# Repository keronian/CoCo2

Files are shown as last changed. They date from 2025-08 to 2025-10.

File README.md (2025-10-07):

# CoCo2

This is my version of two separate composite video mod boards for the Tandy Color Computer 2, based initially on calphool's work.  One board is, like his, to replace a vertical RF Modulator, the other is to replace a horizontal RF Modulator.  The circuit design is the same for both.

I started with calphool's work, but re-did the whole board in KiCad.  The vertical board has some support PCBs that can be fabricated, and they serve as grounding points... You can use the board without them, but you'd need to use a grounding wire.  Horizontal board is mounted by taking a solder lug, bending the tab 90 degrees, and screwing it up into the board through the standoff (which should be soldered from the top for the best strength).
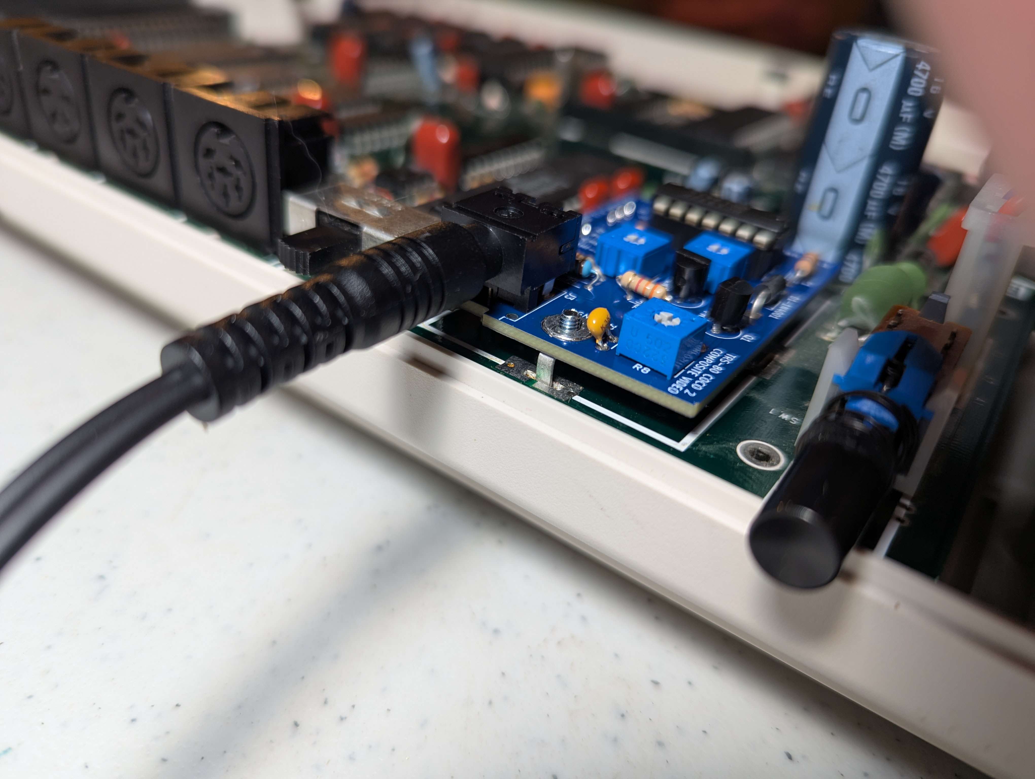
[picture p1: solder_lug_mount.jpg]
Lug Mount

Grounding seems to work great so far, we'll see if I have issues with it backing out.  This is the first time I've tried doing anything with KiCad, so... hopefully it's not terrible.

With some advice from captainkirchoff in Discord, I've tweaked some resistors and added a circuit that let the channel select switch disable color.  Please note that this is really only for monochrome monitors, as it completely suppresses the chroma signal, which causes some weird artifacting in many color monitors.

Vertical version has also had a switch added to replicate the same functionality for that board... I used a SLW-1298856-5A-RA-N-D (will be in the BOM) - Had to import the footprint for it, so if you work on the board you'll need to grab that library from them.

Note that you can increase the value of the C4 capacitor and get better noise reduction (suggested value can go up to 10uF), but ceramic caps are still preferred.

The vertical board's support brackets are set up so that you can slip a thin metal tab (I cut a piece off of one of the solder lugs in the BOM) into the slot after it's slotted into the board, then you add solder to create the joint.
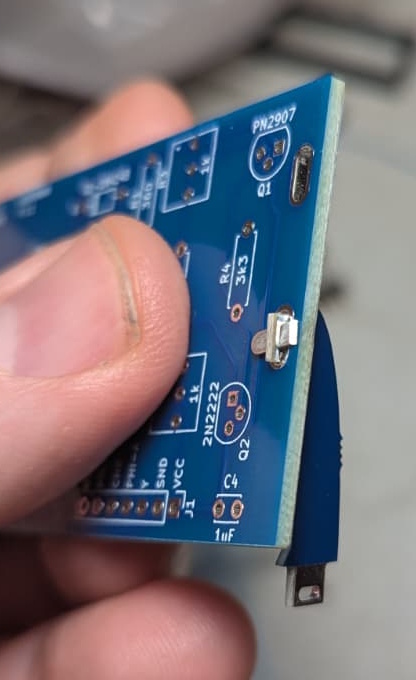
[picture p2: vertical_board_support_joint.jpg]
Vertical Board Support Joint


Overall fitment suggestion would be to solder the smaller supports to the back side of the board along with the headers (the size of header is VERY important, the BOM has the right size) - Then you slip it into place on the board with the longer supports just dry fit.. make sure everything is where you want it, then solder the longer supports into place, and finish by soldering the underside of the motherboard.  On mine, this resulted in a very solidly mounted board that would hardly wiggle.

https://www.digikey.com/en/mylists/list/GH709EISJW - This is the parts list for the board, with the updated transistors to make sure they were options that would be available and an audio jack that should fit the footprint I had on the board.

# Horizontal Board pics

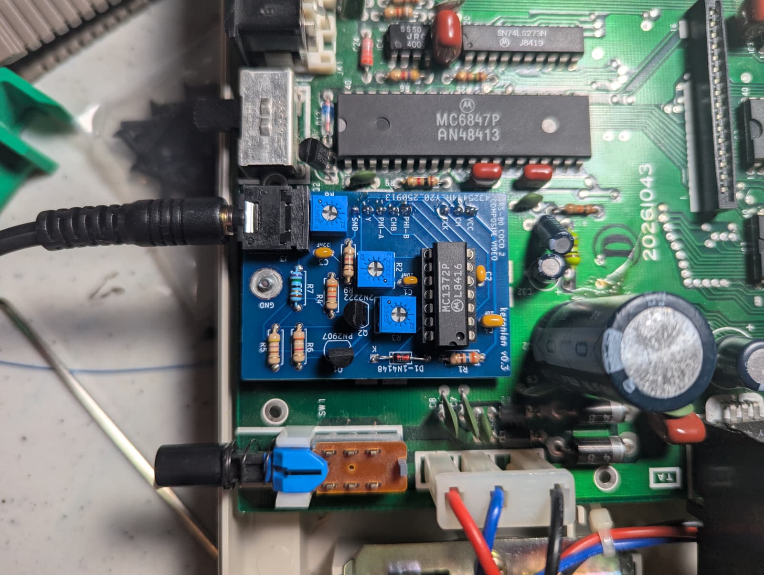
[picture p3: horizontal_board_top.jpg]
Horizontal Board Top

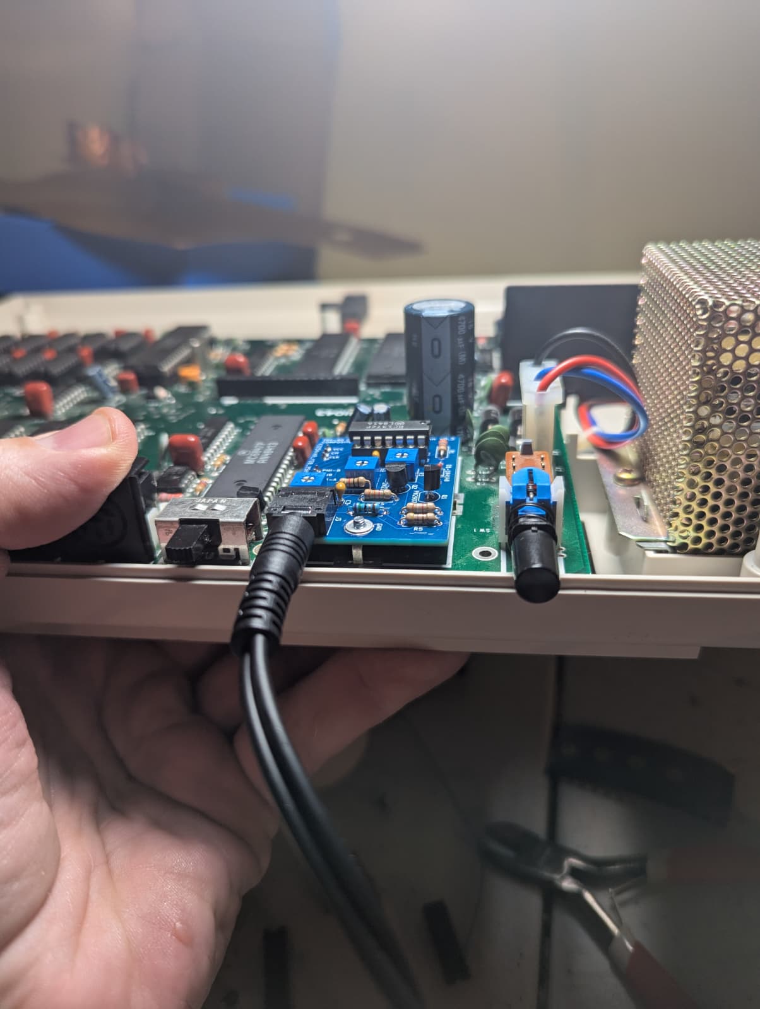
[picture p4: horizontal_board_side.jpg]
Horizontal Board Side


# Vertical Board pics

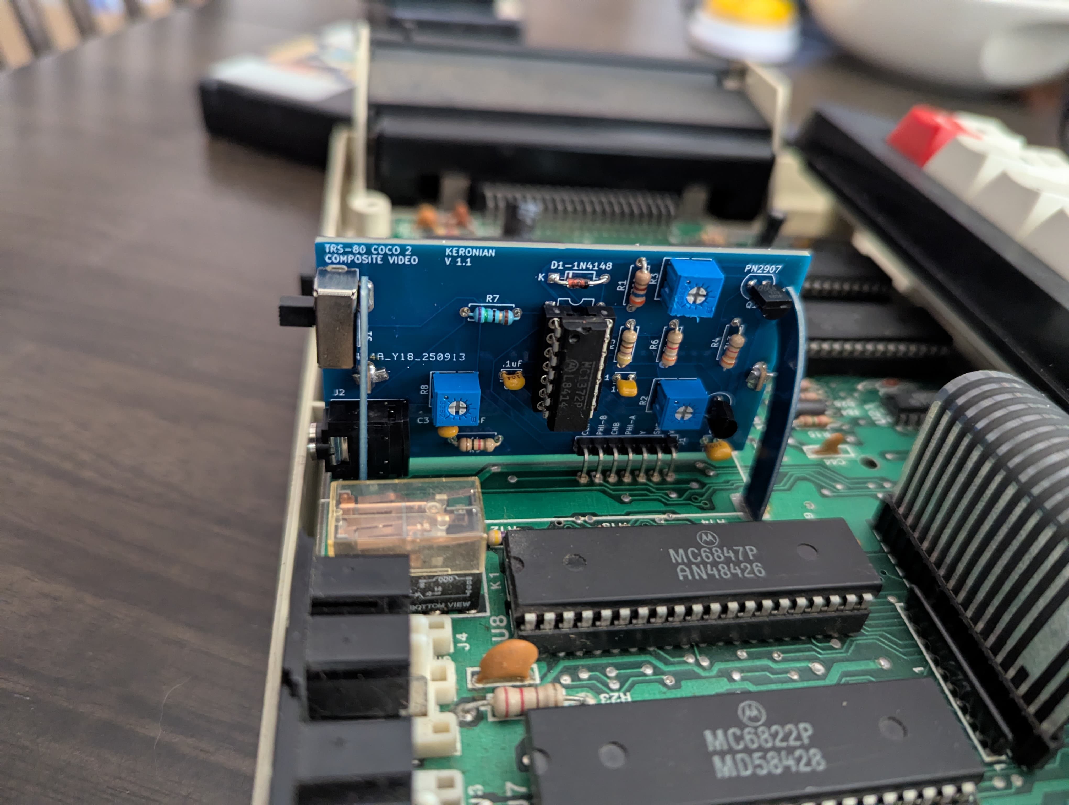
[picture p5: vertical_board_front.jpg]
Vertical Board Top

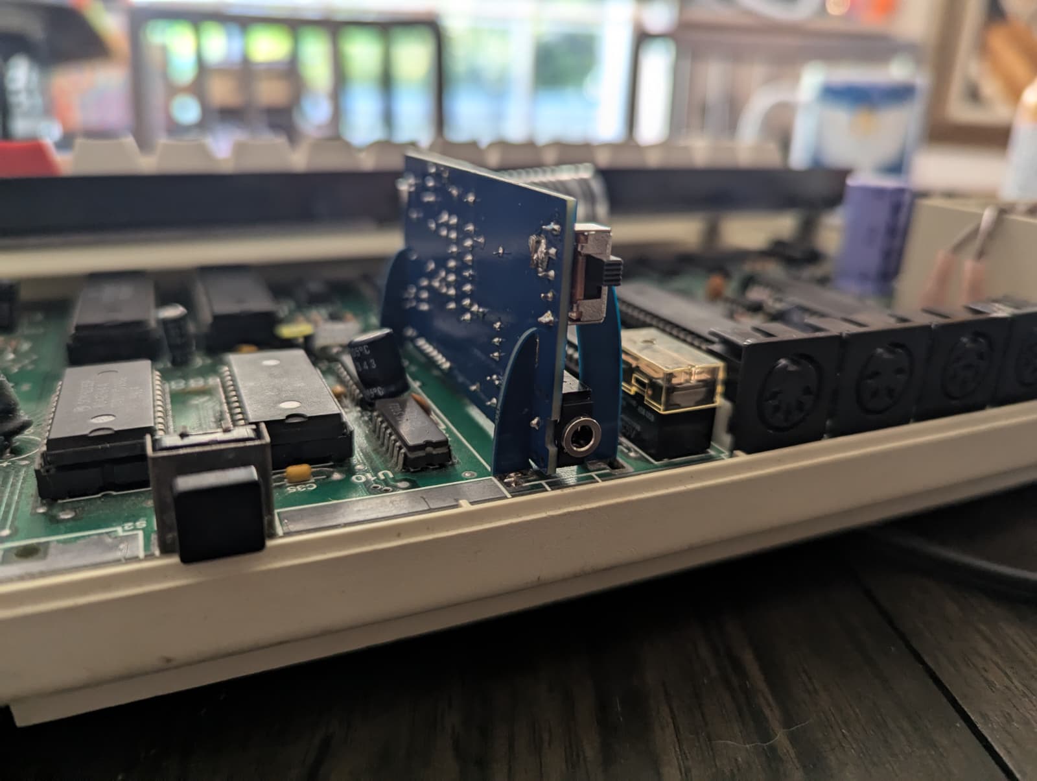
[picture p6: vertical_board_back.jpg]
Vertical Board Side


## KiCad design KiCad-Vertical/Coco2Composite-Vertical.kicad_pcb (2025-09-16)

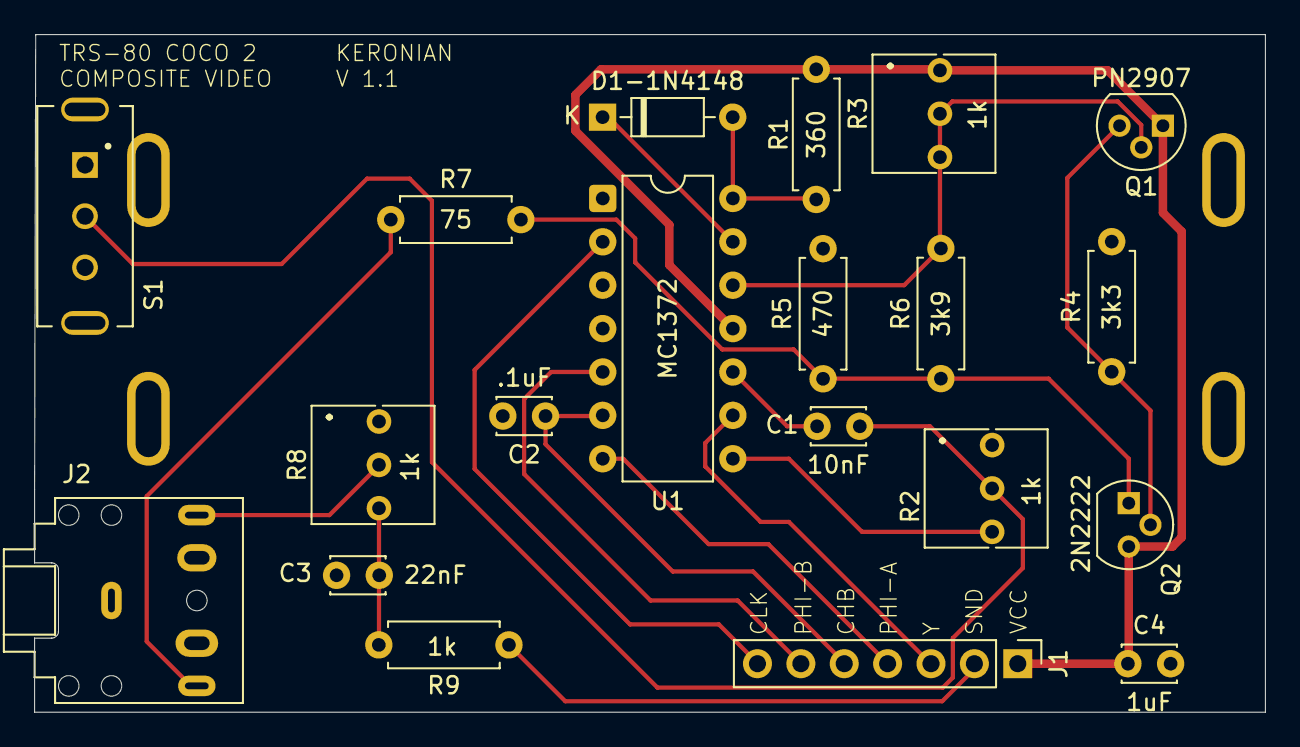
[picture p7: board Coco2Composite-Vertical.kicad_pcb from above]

Board: 2 copper layers, 72.1 x 39.7 mm, 20 parts (0 on the bottom side), 19 nets.

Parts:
C1: 10nF; C_Disc_D3.0mm_W2.0mm_P2.50mm
C2: .1uF; C_Disc_D3.0mm_W2.0mm_P2.50mm
C3: 22nF; C_Disc_D3.0mm_W2.0mm_P2.50mm
C4: 1uF; C_Disc_D3.0mm_W2.0mm_P2.50mm
D1-1N4148: 1N4148; D_DO-35_SOD27_P7.62mm_Horizontal
J1: TO_COCO2; PinHeader_1x07_P2.54mm_Vertical
J2: AUDIO_JACK_3.5MM_KIT; Jack_3.5mm_CUI_SJ1-3525N_Horizontal
Q1: PN2907; TO-92
Q2: 2N2222; TO-92
R1: 360; R_Axial_DIN0207_L6.3mm_D2.5mm_P7.62mm_Horizontal
R2, R3, R8: 1k; Potentiometer_Bourns_3266Y_Vertical
R4: 3k3; R_Axial_DIN0207_L6.3mm_D2.5mm_P7.62mm_Horizontal
R5: 470; R_Axial_DIN0207_L6.3mm_D2.5mm_P7.62mm_Horizontal
R6: 3k9; R_Axial_DIN0207_L6.3mm_D2.5mm_P7.62mm_Horizontal
R7: 75; R_Axial_DIN0207_L6.3mm_D2.5mm_P7.62mm_Horizontal
R9: 1k; R_Axial_DIN0207_L6.3mm_D2.5mm_P7.62mm_Horizontal
S1: SLW-1298856-5A-RA-N-D; SW_SLW-1298856-5A-RA-N-D
U1: MC1372; DIP-14_W7.62mm

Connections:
/CHB: C2.1, J1.5, U1.6 (COL_REF_IN)
/CLK: J1.7, U1.2 (OSC_IN)
/COMP_OUT: J2.T, R7.1
/PHI-A: J1.4, U1.7 (COL_A_IN)
/PHI-B: J1.6, U1.5 (COL_B_IN)
/SND: J1.2, R9.1
/SND_OUT: J2.R, R8.2
/Y: J1.3, U1.9 (LUM_IN)
GND: C2.2, C3.2, C4.2, J2.S, R2.1, R4.2, R5.2, R8.1, S1.3, S1.SH1, S1.SH2, U1.4 (GND)
unnamed: C1.2, R2.2, S1.2
unnamed: C3.1, R8.3, R9.2
unnamed: D1-1N4148.2 (A), R1.2, U1.14 (RF_TANK_2)
unnamed: D1-1N4148.1 (K), U1.13 (RF_TANK_1)
unnamed: Q1.3, Q2.2 (B), R4.1
unnamed: Q2.1 (E), R5.1, R6.1, R7.2
unnamed: C1.1, U1.10 (CHROM_IN)
unnamed: R2.3, U1.8 (CHROM_MOD_OUT)
unnamed: Q1.2, R3.2, R3.3, R6.2, U1.12 (RF_OUT)
VCC: C4.1, J1.1, Q1.1, Q2.3 (C), R1.1, R3.1, U1.11 (VCC)

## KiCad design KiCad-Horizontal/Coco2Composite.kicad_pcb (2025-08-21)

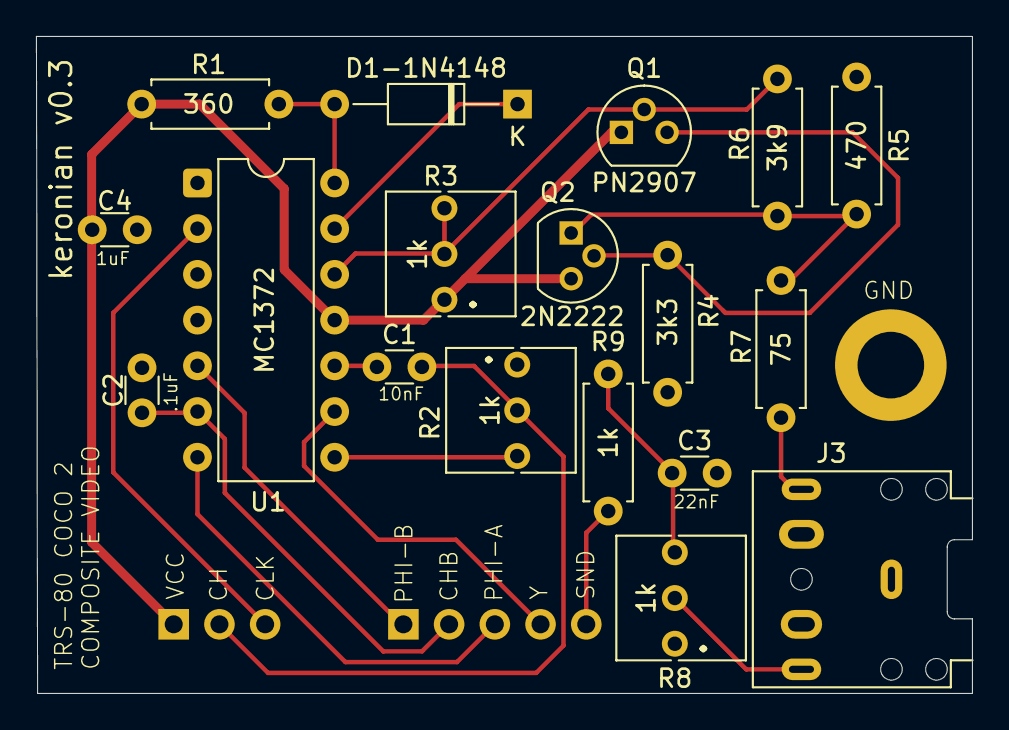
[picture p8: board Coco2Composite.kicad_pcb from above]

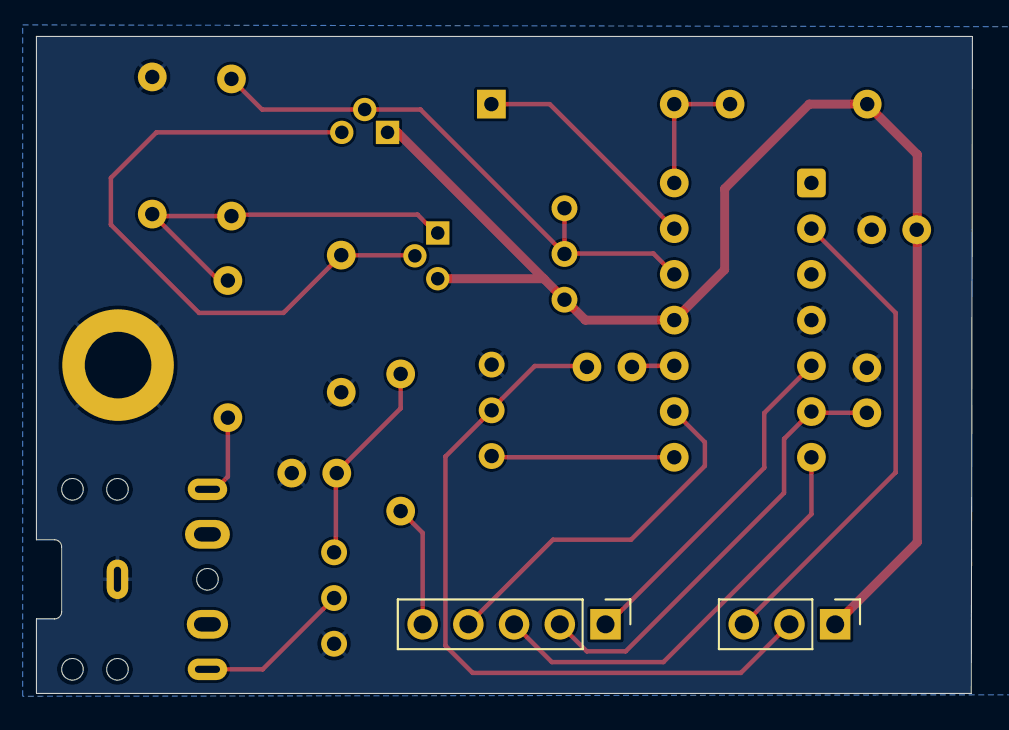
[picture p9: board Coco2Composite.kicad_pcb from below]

Board: 2 copper layers, 52.0 x 36.5 mm, 21 parts (2 on the bottom side), 19 nets.

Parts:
C1: 10nF; C_Disc_D3.0mm_W1.6mm_P2.50mm
C2: .1uF; C_Disc_D3.0mm_W1.6mm_P2.50mm
C3: 22nF; C_Disc_D3.0mm_W1.6mm_P2.50mm
C4: 1uF; C_Disc_D3.0mm_W1.6mm_P2.50mm
D1-1N4148: 1N4148; D_DO-35_SOD27_P10.16mm_Horizontal
J1: MA03-1; PinHeader_1x03_P2.54mm_Vertical
J2: MA05-1; PinHeader_1x05_P2.54mm_Vertical
J3: AUDIO_JACK_3.5MM_PTH; Jack_3.5mm_CUI_SJ1-3525N_Horizontal
PAD1: 2,54/0,8; MountingHole_3.7mm_Pad
Q1: PN2907; TO-92
Q2: 2N2222; TO-92
R1: 360; R_Axial_DIN0207_L6.3mm_D2.5mm_P7.62mm_Horizontal
R2, R3, R8: 1k; Potentiometer_Bourns_3266Y_Vertical
R4: 3k3; R_Axial_DIN0207_L6.3mm_D2.5mm_P7.62mm_Horizontal
R5: 470; R_Axial_DIN0207_L6.3mm_D2.5mm_P7.62mm_Horizontal
R6: 3k9; R_Axial_DIN0207_L6.3mm_D2.5mm_P7.62mm_Horizontal
R7: 75; R_Axial_DIN0207_L6.3mm_D2.5mm_P7.62mm_Horizontal
R9: 1k; R_Axial_DIN0207_L6.3mm_D2.5mm_P7.62mm_Horizontal
U1: MC1372; DIP-14_W7.62mm

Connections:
/CH: C1.2, J1.2, R2.2
/CHB: C2.1, J2.2, U1.6 (COL_REF_IN)
/CHROM_IN: C1.1, U1.10 (CHROM_IN)
/CHROM_MOD_OUT: R2.3, U1.8 (CHROM_MOD_OUT)
/CLK: J1.3, U1.2 (OSC_IN)
/COMP_OUT: J3.T, R7.2
/PHI-A: J2.3, U1.7 (COL_A_IN)
/PHI-B: J2.1, U1.5 (COL_B_IN)
/Q1_E: Q1.3, Q2.2 (B), R4.2
/Q2_E: Q2.1 (E), R5.2, R6.2, R7.1
/RF_OUT: Q1.2, R3.2, R3.3, R6.1, U1.12 (RF_OUT)
/RF_TANK_1: D1-1N4148.1, U1.13 (RF_TANK_1)
/RF_TANK_2: D1-1N4148.2, R1.1, U1.14 (RF_TANK_2)
/SND: J2.5, R9.2
/SND_OUT: J3.R, R8.2
/SND_OUT_RES: C3.1, R8.3, R9.1
/Y: J2.4, U1.9 (LUM_IN)
GND: C2.2, C3.2, C4.2, J3.S, PAD1.1, R2.1, R4.1, R5.1, R8.1, U1.4 (GND)
VCC: C4.1, J1.1, Q1.1, Q2.3 (C), R1.2, R3.1, U1.11 (VCC)

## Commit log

2025-07-23 Tried making a version for the horizontal RF mod
    [Coco2Composite.brd, Coco2Composite.sch]
2025-07-25 Added KiCad and digikey parts list
    [Coco2Composite.kicad_pcb, Coco2Composite.kicad_sch]
2025-07-26 Updated KiCad based on board schematic
    [Coco2Composite.kicad_pcb, Coco2Composite.kicad_sch]
2025-07-26 Removed the EAGLE version as it's not really useful at this point
    [Coco2Composite.brd, Coco2Composite.sch]
2025-07-26 updated layout, shifted headers a tiny bit
    [Coco2Composite.kicad_pcb]
2025-07-26 updated layout to try to simplify routes
    [Coco2Composite.kicad_pcb]
2025-07-26 simplified layout & added username
    [Coco2Composite.kicad_pcb]
2025-07-26 updated labels
    [Coco2Composite.kicad_pcb]
2025-07-26 fixed missing ground connection on audio jack
    [Coco2Composite.kicad_pcb]
2025-07-26 fixed missing VCC connection on R3
    [Coco2Composite.kicad_pcb]
2025-07-28 moved ground pad to hopefully have it work as a support strut anchor point
    [Coco2Composite.kicad_pcb, Coco2Composite.kicad_sch]
2025-07-28 Minor tweaks
    [Coco2Composite.kicad_pcb, Coco2Composite.kicad_sch]
2025-07-29 Added gerbers that I sent off to be manufactured for testing
2025-08-06 Moved KiCad files to KiCad-Horizontal directory, added KiCad for the vertical entry using the 3.5mm jack
    [Coco2Composite-Vertical.kicad_pcb, Coco2Composite-Vertical.kicad_sch, Coco2Composite.kicad_pcb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]
2025-08-06 Fixed a missed ground in the vertical board
    [Coco2Composite-Vertical.kicad_pcb]
2025-08-06 realized I missed some ground and vcc pins
    [Coco2Composite.kicad_pcb]
2025-08-06 Modified the silkscreen on the vertical board to make it easier to know where things go
    [Coco2Composite-Vertical.kicad_pcb]
2025-08-06 Updated the vertical model to let the resistors lie down on the board, kept the old one in case someone wants the board the same way it was
    [Coco2Composite-Vertical.kicad_pcb, Coco2Composite-Vertical.kicad_sch]
2025-08-08 removed a pointless trace
    [Coco2Composite.kicad_pcb]
2025-08-08 Increased the footprint for the resistors since the one I picked was still too small
    [Coco2Composite-Vertical.kicad_pcb, Coco2Composite-Vertical.kicad_sch, Coco2Composite.kicad_pcb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]
2025-08-08 minor updates to the vertical PCB to clean up trace paths
    [Coco2Composite-Vertical.kicad_pcb]
2025-08-08 removed the gerbers for the smaller resistor footprint
2025-08-14 Moved the audio jack over a little to make it a bit better centered
    [Coco2Composite.kicad_pcb]
2025-08-14 added a picture of the finished board with an image of the lug mount
2025-08-15 Big changes to let the channel select switch disable color
    [Coco2Composite.kicad_pcb, Coco2Composite.kicad_sch]
2025-08-15 increased the footprint of the variable resistors to match what I have in the BOM, added a dot for orientation, switched schematic symbols to something more standard
    [Coco2Composite.kicad_pcb, Coco2Composite.kicad_sch]
2025-08-15 Changed diode footprint for smaller diode
    [Coco2Composite.kicad_pcb, Coco2Composite.kicad_sch]
2025-08-15 Reworked traces to keep them all on the front, shrunk trace width to 0.25
    [Coco2Composite.kicad_pcb]
2025-08-15 Added a supply bypass capacitor
    [Coco2Composite.kicad_pcb, Coco2Composite.kicad_sch]
2025-08-16 Overhauled vertical board based on lessons learned working on horizontal board
    [Coco2Composite-Vertical.kicad_pcb, Coco2Composite-Vertical.kicad_sch]
2025-08-16 Fixed label on diode
    [Coco2Composite-Vertical.kicad_pcb, Coco2Composite-Vertical.kicad_sch]
2025-08-16 Fixed the bypass cap on the schematic
    [Coco2Composite.kicad_sch]
2025-08-16 Updated some schematic symbols and rerouted a few things on the vertical board
    [Coco2Composite-Vertical.kicad_pcb, Coco2Composite-Vertical.kicad_sch]
2025-08-18 Added color switch to vertical board
    [Coco2Composite-Vertical.kicad_pcb, Coco2Composite-Vertical.kicad_sch]
2025-08-18 shifted the labels on J1 up to match the move of the header
    [Coco2Composite-Vertical.kicad_pcb]
2025-08-18 Fixed associations and made cap value visible for vert board
    [Coco2Composite-Vertical.kicad_pcb, Coco2Composite-Vertical.kicad_sch]
2025-08-21 fixed the board outline to be more consistent so you can export STEP files and such
    [Coco2Composite.kicad_pcb]
2025-09-16 Added supports for vertical board
    [Coco2Composite-Vertical.kicad_pcb, Coco2Composite-Vertical.kicad_sch]
2025-09-29 Updated vertical board based on header selection and switch positioning, added pictures of horizontal board
2025-10-05 Added vertical board pics
